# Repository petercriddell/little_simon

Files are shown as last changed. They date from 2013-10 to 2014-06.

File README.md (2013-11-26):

little_simon
============

little_simon is an interactive work based on the classic game and powered by the Attiny44

Files
=====

/docs - PDF of assembly guide for kit<br>
/hardware - Fritzing design file<br>
/software - Arduino IDE file

License Information
===================

<br /><span xmlns:dct="http://purl.org/dc/terms/" property="dct:title">'little_simon' hardware design</span> by <a xmlns:cc="http://creativecommons.org/ns#" href="http://fritzing.org/projects/arduino-simon" property="cc:attributionName" rel="cc:attributionURL">Peter C. Riddell</a> is licensed under a <a rel="license" href="http://creativecommons.org/licenses/by-sa/3.0/deed.en_US">Creative Commons Attribution-ShareAlike 3.0 Unported License</a>.<br />Based on a work at <a xmlns:dct="http://purl.org/dc/terms/" href="http://fritzing.org/projects/arduino-simon" rel="dct:source">http://fritzing.org/projects/arduino-simon</a>.<br />Permissions beyond the scope of this license may be available at <a xmlns:cc="http://creativecommons.org/ns#" href="petercriddell@me.com" rel="cc:morePermissions">petercriddell@me.com</a>.<br>
<br>
<br>
<br /><span xmlns:dct="http://purl.org/dc/terms/" property="dct:title">'little_simon' code</span> by <a xmlns:cc="http://creativecommons.org/ns#" href="http://https://github.com/cpswan/Arduino/blob/master/simon.ino" property="cc:attributionName" rel="cc:attributionURL">Peter C. Riddell</a> is licensed under a <a rel="license" href="http://creativecommons.org/licenses/by-sa/3.0/deed.en_US">Creative Commons Attribution-ShareAlike 3.0 Unported License</a>.<br />Based on a work at <a xmlns:dct="http://purl.org/dc/terms/" href="http://fritzing.org/projects/arduino-simon" rel="dct:source">http://fritzing.org/projects/arduino-simon</a>.<br />Permissions beyond the scope of this license may be available at <a xmlns:cc="http://creativecommons.org/ns#" href="http://blog.thestateofme.com/2012/01/11/arduino-simon/" rel="cc:morePermissions">http://blog.thestateofme.com/2012/01/11/arduino-simon/</a>.

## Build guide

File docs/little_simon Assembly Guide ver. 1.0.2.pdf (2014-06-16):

little_simon Assembly Guide ver. 1.0.2

# little_simon Assembly Guide

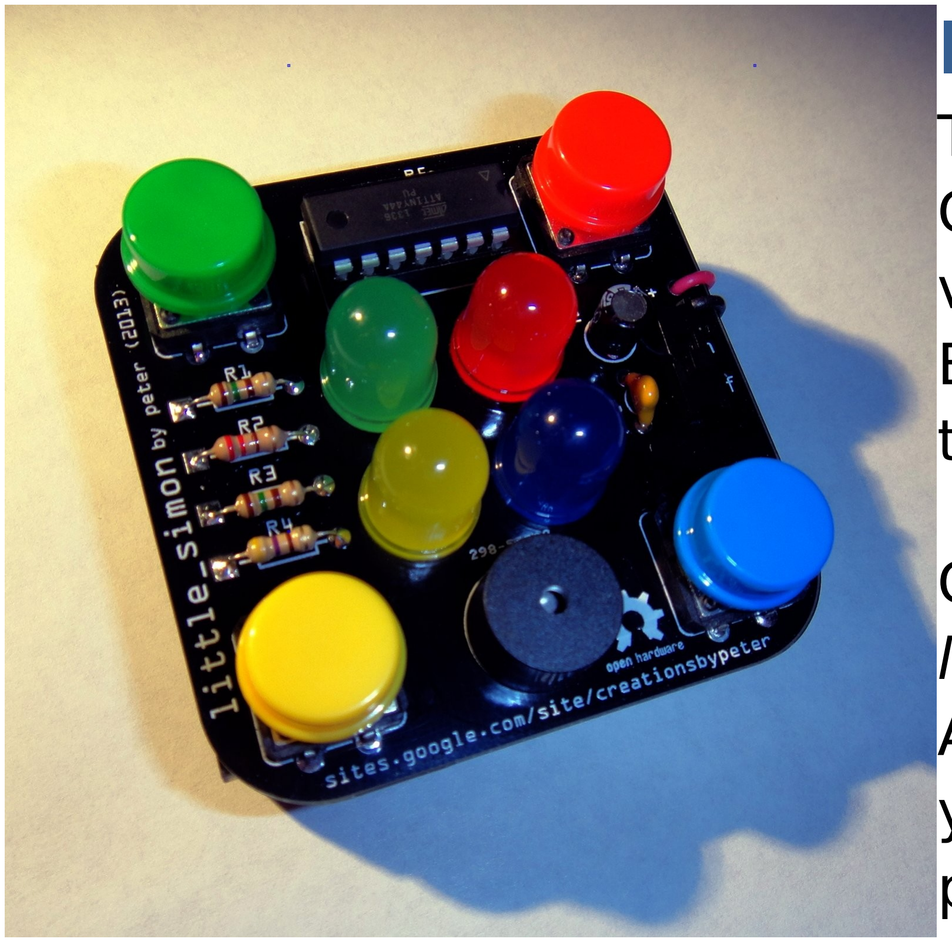
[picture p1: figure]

### Introduction

Thank you for purchasing a little_simon kit from Creations by Peter! little_simon is a simplified version of the classic 1978 game from Milton Bradley. These are hand-made and programmed by the creator in Gilbert, AZ.

Gameplay is simple; just repeat each sequence that little_simon plays you using the colored buttons. Another step is added to the sequence each time you get it right. If you get it wrong little_simon will play a 'raspberry' noise and flash the step you got wrong twice. If you make it all the way to the end, little_simon plays a little light show to congratulate you! A new game then begins. little_simon is programmed to go up to 14 steps, which was the intermediate level in the original game.

The circuit for little_simon is fairly straightforward, as shown in the illustration 2.

Illustration 1: little_simon as
assembled

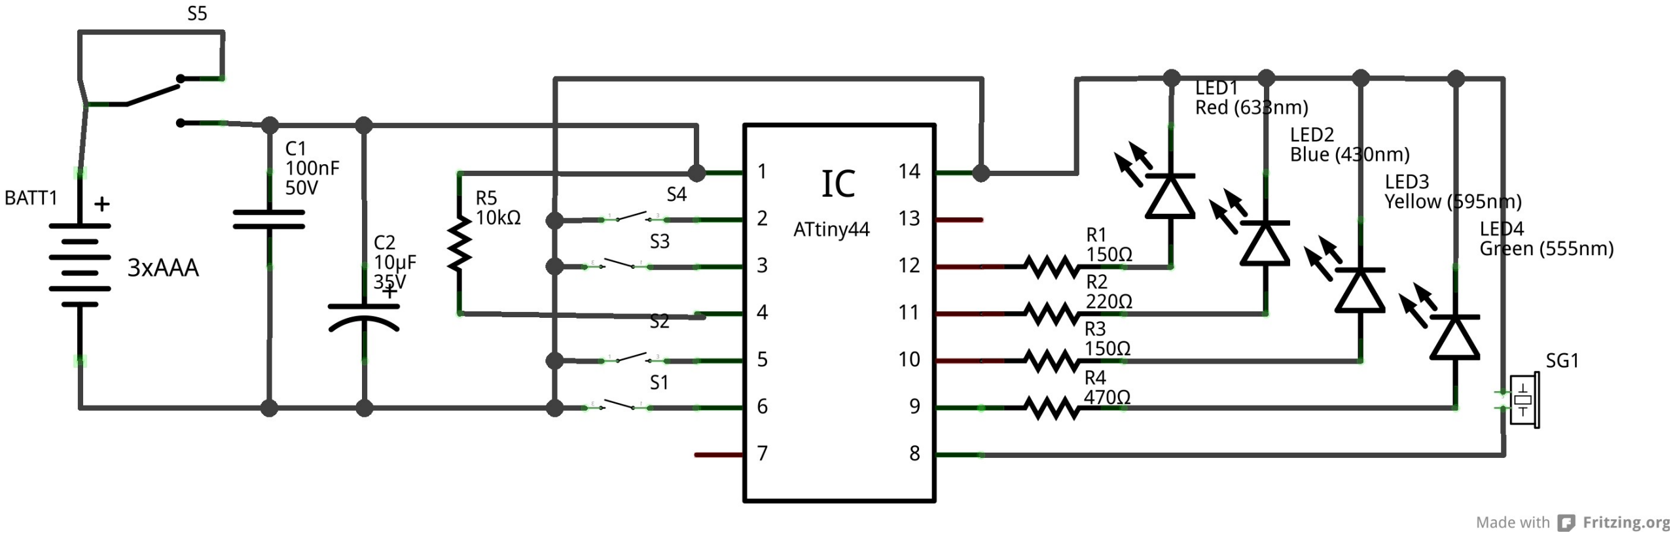
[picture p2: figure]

Illustration 2: schematic diagram of little_simon

### Soldering Skill

You’ll need some basic soldering skills in order to assemble little_simon. Don’t be intimidated if this is your first time soldering, as it just requires a little attention to detail and some patience. Great soldering tutorials online at places like www.Sparkfun.com, www.Adafruit.com, and even NASA has a tutorial at radiojove.gsfc.nasa.gov/telescope/soldering.htm.

### Things You’ll Need

You’ll need some basic soldering and hand tools to complete little_simon. Many of these items can be acquired for very little cost at big-box discount stores, well stocked craft centers, and electronic stores. The hot-glue gun, for example, can be found in the craft section of big ‘mart’ style stores for under $3!

Here are some things to have on hand when you begin assembly:

Safety glasses | Small needle-nose pliers | Paper towels

Soldering iron or station 63-37 flux core solder,

| 0.025” | Hot-glue gun (high-temp)
Tip-cleaning sponge | Flux-pen (optional) | Hot-glue sticks (multi-temp)
Flush-cut wire cutters | Rubber Band | Panavise Jr. or similar (optional)
Wire stripping tool | Rubbing alcohol | 3 AA batteries
Cotton swabs | Multimeter (optional) | Green Scotch-Brite pad (optional)

### Parts List

Check the contents of the kit against Table 1.

Quantity | Part | Description
1 | BATT1 | 3xAA Battery-holder
1 | C1 | 0.1 µF Ceramic Capacitor
1 | C2 | 10 µF Electrolytic Capacitor
4 | Key Caps | Red, Blue, Yellow, Green
1 | LED1 | Red LED - 10mm
1 | LED2 | Blue LED – 10mm
1 | LED3 | Yellow LED – 10mm
1 | LED4 | Green LED – 10mm
1 | PCB1 | little_simon circuit board
2 | R1, R3 | 150 Ω Resistor
1 | R2 | 220 Ω Resistor
1 | R4 | 470 Ω Resistor
1 | R5 | 10k Ω Resistor
4 | S1, S2, S3, S4 | 12mm Tactile Switch
1 | S5 | Slide Switch
1 | SG1 | 12mm Buzzer
1 | U1 | Preprogrammed ATtiny44A micro-controller
1 | U1_SOCKET | Socket for U1

Table 1: parts list

### Before you begin…

Here are a few things you might find helpful:

ü Read the entire guide before you start. E-mail if you have any questions.

ü Cleaning all the component leads with a cotton-swab and rubbing alcohol helps reduce the likelihood of soldering problems.

ü Use good quality solder. Consider the ‘no-clean’ type so you can skip cleaning the flux from the bottom of the board. Good solder costs a little more, but the results are worth it. MG Chemicals 63/37 flux core solder (cat. no. 4884) was used in the development of little_simon.

ü You don’t need the most expensive tools to get great results. Simple equipment from a discount ‘Mart’ type store or Harbor Freight will be more than adequate. Check the craft aisle for small pliers and wire cutters.

ü Use a 25-40watt soldering iron. Again, you don’t need a super-expensive iron.

ü Figure 3 is a picture of PCB1 included for your reference

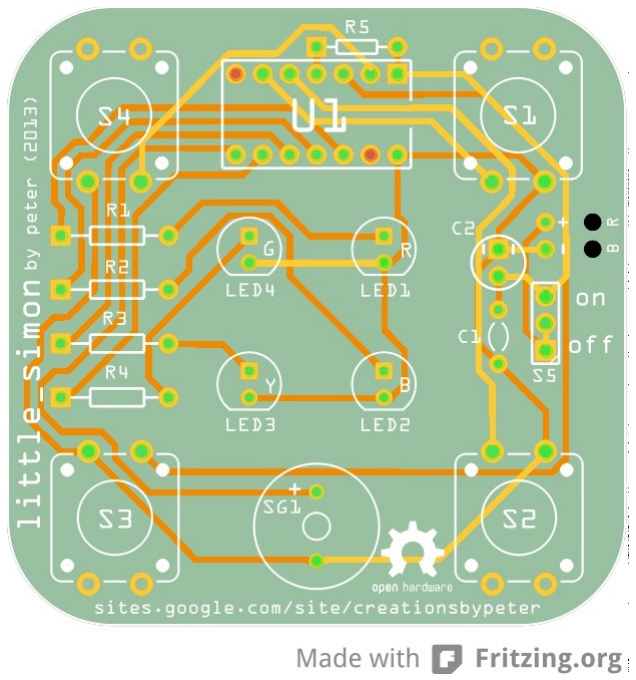
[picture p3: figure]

Illustration 3: PCB1

### Assembly

1. Clean both sides of PCB1 with a paper towel and some rubbing alcohol.
2. Insert LED1 (red), LED2 (blue), LED3 (yellow) and LED4 (green) onto PCB1 while being careful to observe polarity—the longer lead is the anode and goes into the square solder-pad of each LED position marked on the board¹
. Spread
the leads apart to keep the LEDs in place for soldering. Solder the LEDs in place and trim the excess from the leads.
3. Insert R1 through R4 into PCB1 as marked. Use Table 2 as a reference.
Part | Value | Color Code
R1 | 150 Ω | Brown-Green-Brown-Gold
R2 | 220 Ω | Red-Red-Brown-Gold
R3 | 150 Ω | Brown-Green-Brown-Gold
R4 | 470 Ω | Yellow-Violet-Brown-Gold
4. Bend the leads of the resistors R1 through R4 outwards slightly to keep them in place for soldering. Solder the resistors in place and trim the excess from the leads.
5. Insert the U1_SOCKET into PCB1 so the indentation on one end is closest to notch (gap) on the right side of the U1 outline. Use the rubber band to hold the socket in place. Solder two socket pins on opposite corners (doesn’t matter which corners) of U1_SOCKET in place. Remove the rubber band and solder the rest of the pins in place and clip the excess from the pins.
6. Insert R5 (the tiny resistor) into PCB1 as marked. Bend the leads outwards slightly to hold it in place. Solder R5 in place and clip the excess from the leads.
7. Before you can install the S1-S4 tact-switches you'll need to cut off the small plastic pins protruding from the back of the switches. Use your flush cutters to do this. Now insert the for tact-switches into PCB1 as indicated on the board. Use a rubber-bands wrapped around the board to hold them in place while soldering. Solder two pins from opposite corners of each switch in

1 While the outlines on the board show a flat-side marking the cathode, the LEDS themselves do NOT have a flat side. The anode is the longer lead. Trim the leads only AFTER you are certain that the LEDs are soldered in place correctly.

place, then remove the rubber bands. Make sure the switches are all reasonably flush against the board. Solder the remaining pins in place. Clip the excess from the pins.

8. Insert the buzzer SG1 into PCB1 as marked making sure it is flush against the board. Be sure to observe polarity—the longer lead is positive (+). Hold SG1 in place with a rubber-band and solder the leads. Trim the excess
9. Now it’s time to install BATT1 battery-holder. You may want to shorten the leads a bit (try 2” or so). Strip ¼” from the ends of the leads and tin the bare wire with solder.

10.Thread the BATT1 leads through the top of the PCB into the two holes located on the far right-side of the board. Make sure the red (+) lead goes through the hole marked 'R' and the black (-) lead through the hole marked 'B.' Note that the holes correspond to the BATT1 solder-pads.

11.Now insert the tinned ends of the BATT1 leads up through the corresponding BATT1 holes located on the lower-right side of the board. Be careful to observe polarity; the red lead is soldered into the pad marked '+' and the black lead is soldered into the pad marked '-.' Solder the BATT1 leads from the top side of the board. Clip the excess from the leads.

12.Now pull the slack wire back through the holes so they are flush against the bottom of the board. Now that the battery-holder is on, be sure to handle little_simon so as not to put to much stress on the battery-holder leads.

13.Install slide-switch S5 into PCB1 as marked. S5 is not polarized, so you may install it in either direction. Hold S5 in place for soldering with tape or a rubber-band. Make sure it is flush against the board. Solder S5 in place. Clip the excess from the leads.

14.Install C2 (the larger electrolytic capacitor) into PCB1 as marked being careful to observe polarity. Note that the negative lead is shorter and goes into the square pad. Bend the leads outwards slightly to hold it in place. Solder C2 in place and clip the excess from the leads.

15.Install C1 into PCB1 as marked. C1 is not polarized and can be installed in either direction. Bend the leads outwards slightly to hold it in place. Solder C1 in place and clip the excess from the leads.

16.Insert U1 into the socket on the PCB, making sure the silver dot is closest to the notch at one end of the socket. Note that U1 also has a moon-shaped indentation at one end near the silver dot (the dot marks the chip as having been programmed). Double check that U1 is inserted correctly and completely into the board.

17.It’s time to test little_simon for the first time! Make sure the switch S5 is in the ‘off’ position. Insert three AA batteries into the battery holder. IT’S VERY IMPORTANT TO TEST LITTLE_SIMON BEFORE YOU GLUE IT TO THE BATTERY HOLDER! It will be much easier to correct any problems if you have access to the solder joints on the back of the board!

18.Slide switch S5 to the ‘on’ position. There will be a short 'roulette' display with sound, a pause, then game-play will start. Follow along with the switches to make sure they all work. If you’re having any difficulties check the troubleshooting section of this guide.

19.Now that your little_simon is working, you can glue the battery holder to the bottom of PCB1 with a hot-glue gun. While you’re heating up the glue gun, clean the top of the battery holder with some rubbing alcohol and a paper towel. Scuffing the top surface of the battery holder with a green Scotch-Brite pad will help the hot-glue stick much better.

20.Apply two generous globs of hot-glue to the top of the battery holder on either side of the wire running across the top of the battery holder. Don’t get too much on the wire. Now press PCB1 onto the glue and hold it down on the battery holder, aligning the battery-holder so it’s edges are flush with the sides and centered between the top and bottom of PCB1 before the glue sets.

21. Now snap the corresponding colored key-caps onto the four tact-switches. S1 is red, S2 is blue, S3 is yellow and S4 is green.

22.Your little_simon is finished! Turn it on and and start having fun!

### Troubleshooting Tips

Here’s a few thing to check if little_simon doesn’t work when you turn it on:

ü Make sure the batteries are fresh and inserted correctly.

ü Make sure U1 is inserted with the correct orientation

ü Double check the polarity of the LEDs and C2.

ü Double check the polarity of the BATT1 battery holder leads.

ü Check to see if you missed any soldering joints.

ü Check for cold soldering joints. Use a cotton swab soaked in alcohol to clean away the flux on any suspect joints when checking.

ü If you have a multimeter, check that there is about 4.5 volts DC at the BATT1 soldering joints on the PCB1. If not, remove and re-insert the batteries and check again.

ü Rubbing alcohol can be used to release the hot glue after it’s cooled if you need to remove the battery holder. Just drizzle some on and start to gently pull the holder away from PCB1, adding more alcohol as needed. Be gentle and persistent and the battery holder will come off. Be sure to let the excess alcohol dry before re-installing the battery holder.

### Contact

If you have questions about the instructions or if you find any errors you can send e-mail to petercriddell@me.com. For additional information about little_simon please visit https://github.com/petercriddell/little_simon. You can also see more pictures and a video of little_simon in action at https://sites.google.com/site/creationsbypeter/.

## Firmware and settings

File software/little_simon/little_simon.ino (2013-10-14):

/*little_simon
 ============
 
 "little_simon" was derived from "Arduino Simon" by Chris Swan and
 used under a Creative Commons Attribution-ShareAlike 3.0
 Unported License: http://creativecommons.org/licenses/by-sa/3.0/.
 "little_simon" is licensed under the same Creative Commons
 Attribution-ShareAlike 3.0 Unported License: http://creativecommons.org/licenses/by-sa/3.0/
 
 The original code for "Arduino Simon" is available at the Fritzing
 website: http://fritzing.org/projects/arduino-simon. You can also 
 find it at GitHub: https://github.com/cpswan/Arduino
 
 When compiling and uploading "little_simon" to the target ATtiny44,
 be sure to use the MIT-HLT board definitions. Under tools select
 'ATtiny44 (internal 8 MHz clock) then burn bootloader to the 
 target. See the MIT High-Low tech website at http://hlt.media.mit.edu/?p=1695
 for more information on how to use Arduino IDE for programming
 AVR microcontrollers.
 */

const int led_red = 1;         // Output pins for the LEDs
const int led_blue = 2;
const int led_yellow = 3;
const int led_green = 4;
const int buzzer = 5;		 // Output pin for the buzzer
const int random_seed = 0;        // Unconnected pin used for random seed generation
const int red_button = 9;      // Input pins for the buttons
const int blue_button = 10;
const int yellow_button = 6; 
const int green_button = 7;   // Pin 13 is special - didn't work as planned
const int unused = 8;
long sequence[20];             // Array to hold sequence
int count = 0;                 // Sequence counter
long input = 5;                // Button indicator
int wait = 500;                // Variable delay as sequence gets longer
int test_count = 0;            // Counter for power-on test function
const int test_num = 3;              // Number of times power-on test is repeated  
const int test_time = 100;           // Length of time for each step of test sequence in millis
/*
  playtone function taken from Oomlout sample
 takes a tone variable that is half the period of desired frequency
 and a duration in milliseconds
 */
void playtone(int tone, int duration) {
  for (long i = 0; i < duration * 1000L; i += tone *2) {
    digitalWrite(buzzer, HIGH);
    delayMicroseconds(tone);
    digitalWrite(buzzer, LOW);
    delayMicroseconds(tone);
  }
}


/*
  functions to flash LEDs and play corresponding tones
 very simple - turn LED on, play tone for .5s, turn LED off
 */
void flash_red() {
  digitalWrite(led_red, HIGH);
  playtone(2273,wait);             // low A
  digitalWrite(led_red, LOW);
}

void flash_blue() {
  digitalWrite(led_blue, HIGH);
  playtone(1700,wait);             // D
  digitalWrite(led_blue, LOW);
}

void flash_yellow() {
  digitalWrite(led_yellow, HIGH);
  playtone(1275,wait);             // G
  digitalWrite(led_yellow, LOW);
} 

void flash_green() {
  digitalWrite(led_green, HIGH);
  playtone(1136,wait);             // high A
  digitalWrite(led_green, LOW);
}

// a simple power-on test function to flash all of the LEDs in turn
void runtest() {
  for(test_count = 0; test_count < test_num; test_count++) {
    digitalWrite(led_red, HIGH);      // Turn on LED
    playtone(2273,test_time);        // Play corresponding tone for specified test_time
    digitalWrite(led_red, LOW);      // Turn of LED
    digitalWrite(led_blue, HIGH);      // Turn on LED
    playtone(1700,test_time);        // Play corresponding tone for specified test_time
    digitalWrite(led_blue, LOW);      // Turn of LED
    digitalWrite(led_yellow, HIGH);      // Turn on LED
    playtone(1275,test_time);        // Play corresponding tone for specified test_time
    digitalWrite(led_yellow, LOW);      // Turn of LED
    digitalWrite(led_green, HIGH);      // Turn on LED
    playtone(1136,test_time);        // Play corresponding tone for specified test_time
    digitalWrite(led_green, LOW);      // Turn of LED
  }
  // Test Pattern from Chris Swan's original code
  //    flash_red();
  //    flash_green();
  //    flash_yellow();
  //    flash_blue();  
}

/* a function to flash the LED corresponding to what is held
 in the sequence
 */
void squark(long led) {
  switch (led) {
  case 0:
    flash_red();
    break;
  case 1:
    flash_green();
    break;
  case 2:
    flash_yellow();
    break;
  case 3:
    flash_blue();
    break;
  }
  delay(50);
}

// function to congratulate winning sequence
void congratulate() {
  digitalWrite(led_red, HIGH);       // turn all LEDs on
  digitalWrite(led_green, HIGH);
  digitalWrite(led_yellow, HIGH);
  digitalWrite(led_blue, HIGH);
  playtone(1014,250);                // play a jingle
  delay(25);    
  playtone(1014,250);
  delay(25);    
  playtone(1014,250);
  delay(25);    
  playtone(956,500);
  delay(25);    
  playtone(1014,250);
  delay(25);
  playtone(956,500);
  delay(2000);   
  digitalWrite(led_red, LOW);        // turn all LEDs off
  digitalWrite(led_green, LOW);
  digitalWrite(led_yellow, LOW);
  digitalWrite(led_blue, LOW);
  resetCount();                      // reset sequence
}

// function to reset after winning or losing
void resetCount() {
  count = 0;
  wait = 500;
}

// function to build and play the sequence
void playSequence() {
  sequence[count] = random(4);       // add a new value to sequence
  for (int i = 0; i < count; i++) {  // loop for sequence length
    squark(sequence[i]);             // flash/beep
  }
  wait = 500 - (count * 15);         // vary delay
  count++;                           // increment sequence length
}

// function to read sequence from player 
void readSequence() {
  for (int i=1; i < count; i++) {               // loop for sequence length
    while (input==5){                          // wait until button pressed
      if (digitalRead(red_button) == LOW) {    // Red button
        input = 0;
      }
      if (digitalRead(green_button) == LOW) {  // Green button
        input = 1;
      }
      if (digitalRead(yellow_button) == LOW) { // Yellow button
        input = 2;
      }
      if (digitalRead(blue_button) == LOW) {   // Blue button
        input = 3;
      }
    }
    if (sequence[i-1] == input) {              // was it the right button?
      squark(input);                           // flash/buzz
      if (i == 20) {                           // check for correct sequence of 20
        congratulate();                        // congratulate the winner
      }
    }
    else {
      playtone(4545,1000);                   // low tone for fail
      squark(sequence[i-1]);                 // double flash for the right colour
      squark(sequence[i-1]);
      resetCount();                          // reset sequence
    } 
    input = 5;                                   // reset input
  }
}  

// standard sketch setup function
void setup() {
  pinMode(unused, INPUT_PULLUP);      // pin ''unused' is not used, so set to high
  pinMode(led_red, OUTPUT);      // configure LEDs and buzzer on outputs
  pinMode(led_green, OUTPUT); 
  pinMode(led_yellow, OUTPUT); 
  pinMode(led_blue, OUTPUT); 
  pinMode(buzzer, OUTPUT);
  pinMode(red_button, INPUT_PULLUP);    // configure buttons on input
  pinMode(green_button, INPUT_PULLUP);
  pinMode(yellow_button, INPUT_PULLUP);
  pinMode(blue_button, INPUT_PULLUP);
  randomSeed(analogRead(random_seed));     // random seed for sequence generation
  runtest();
}

// standard sketch loop function
void loop() {
  playSequence();  // play the sequence
  readSequence();  // read the sequence
  delay(1000);     // wait a sec
}

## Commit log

2013-10-14 Initial Commit of little_simon files
    little_simon is a simplified version of the classic Milton Bradley game
    powered by the ATtiny44A microcontoller.
    [little_simon.fzz]
2013-11-26 Added docs directory. Added kit assembly guide to docs directory.
2013-11-26 Corrected omission in assembly guide.
2013-11-26 Corrected omission from kit assembly guide.
2013-11-28 Corrected errata in kit assembly guide.
2014-06-16 Updated version of little_simon Assembly Guide adds C1, C2 and S5 installation instructions. Changes references to 'S1' near end of guide to 'S5'. Other typos corrected.
